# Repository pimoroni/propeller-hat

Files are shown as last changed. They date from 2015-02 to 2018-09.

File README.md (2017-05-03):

Propeller HAT

Propeller HAT, the 8-core microcontroller add-on for your Raspberry Pi.

Available now from Pimoroni: http://shop.pimoroni.com/products/propeller-hat



Propeller HAT is licensed under a Creative Commons Attribution-ShareAlike 4.0 International License.: http://creativecommons.org/licenses/by-sa/4.0/

### Features

* 8-core Parallax Microcontroller on-board
* 30 IO pins broken out, serial data/programming connection to Pi
* 20 Pi pins broken out for communications/ease of access
* 170pt breadboard for experimentation
* Python quick start library with PWM/Servo and GPIO libraries

### Getting started

For instant-gratification you can try the Propeller HAT IO libraries:

* [IO using Serial](documentation/Serial-IO.md)
* [IO using i2c](documentation/IO.md)
* [PWM for LEDs/Servos](documentation/PWM.md)

You'll need Propeller IDE to start programming your Propeller HAT:

* [Propeller IDE Getting Started](/documentation/Propeller-IDE-Getting-Started.md)

## Propeller IDE Installation

As always, we've made it super-easy for you to get all the software you need with a nifty one-line installer. To run it fire up Terminal which you'll find in Menu -> Accessories -> Terminal on your Raspberry Pi desktop like so:

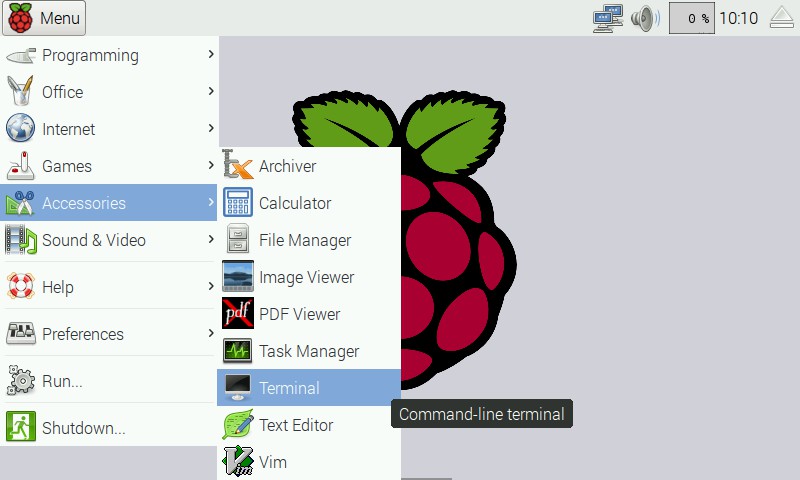
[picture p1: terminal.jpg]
Finding the terminal


In the new terminal window type:

```bash
curl -sS get.pimoroni.com/propellerhat | bash
```

This will install a fairly recent version of the Propeller IDE but if you'd like you can head over to [www.lamestation.com/propelleride/](http://www.lamestation.com/propelleride/) and grab the latest
version of Propeller IDE for the Raspberry Pi, which may be newer than the one installed by the one-line installer.

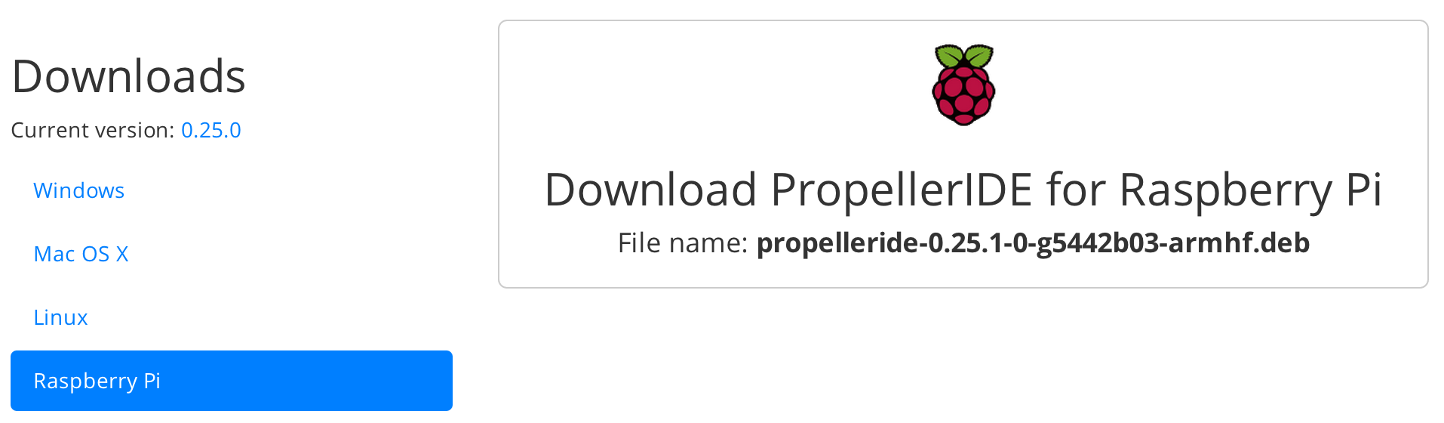
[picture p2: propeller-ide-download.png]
Propeller IDE download


It's easier if you grab the right URL, and use the wget command on your
Raspberry Pi to download it. For example:

```bash
wget https://github.com/parallaxinc/PropellerIDE/releases/download/0.36.7/propelleride-0.36.7-armhf.deb
```

Once downloaded, you can install it with:

```bash
sudo dpkg -i propelleride-0.36.7-armhf.deb
```

### Documentaton & Support

* Tutorials - https://learn.pimoroni.com/propeller-hat
* GPIO Pinout - https://pinout.xyz/pinout/propeller_hat
* Get help - http://forums.pimoroni.com/c/support

### Repository Contents

#### Documentation

Everything you need to get started with Propeller IDE and your first
SPIN program.

#### Software

Suport software and Python-based uploader tool.

* python - Python library for Propeller HAT with PWM and GPIO functions
* sidplay - Play SID tune dumps with Propeller HAT
* p1load - Installer and binary for Pi-compatible p1load

#### Datasheets

Datasheets for Parallax Propeller and Crystal Oscillator.

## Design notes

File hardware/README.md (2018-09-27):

# Propeller HAT Hardware

## License



Propeller HAT is licensed under a Creative Commons Attribution-ShareAlike 4.0 International License.: http://creativecommons.org/licenses/by-sa/4.0/

#### This license covers:

* Propeller HAT board design and schematic layout - Propeller-HAT.brd, Propeller-HAT.sch

#### This license does *not* cover:

* The Parallax Propeller chip itself<sup>1</sup>
* Supporting ICs and components used on the Propeller HAT
* Logos or silkscreen artwork

<sup>1</sup> The Parallax Propeller is licensed under the GNU GPL 3.0, you can find the HDL source to the microcontroller, plus more information, here: http://www.parallax.com/microcontrollers/propeller-1-open-source

#### This license allows you to:

* Share — copy and redistribute the material in any medium or format
* Adapt — remix, transform, and build upon the material for any purpose, even commercially.

#### However, you must:

* give appropriate credit, provide a link to the license, and indicate if changes were made. You may do so in any reasonable manner, but not in any way that suggests we endorse you or your use.
* distribute your contributions under the same license as the original if you remix, transform, or build upon this material.

## Pinout

All Propeller IO is broken out in the horizontal pin headers. Note: The TX/RX pins, while available to the IC as general purpose IO pins normally, are tied to the GPIO of the Raspberry Pi and thus cannot be used.

Pins A29 and A28 are EEPROM SDA and SCL respectively. A 24LC512-I/P<sup>1</sup> EEPROM is recommended, and will require 10K pullup resistors. Once added, the Propeller will allow uploads to EEPROM and will load its contents upon boot.

## Bill Of Materials

* 1 x P8X32A-Q44 - QFP Parallax Propeller IC
* 1 x ABLS3-6.000MHZ-D4Y-T - 6Mhz Crystal Oscillator
* 1 x AP7333-__SRG - 300mA, 3.3V Voltage Regulator
* 1 x EEPROM - for Raspberry HAT compatibility
* 1 x 40PIN Low Profile Female SMD Header
* 1 x 10K Resistor R0603
* 2 x 4.7K Resistor R0603
* 1 x 1K Resistor R0603
* 4 x 0.1uF Capacitor C0603K
* 2 x 1uF Capacitor C0603K

## Crystal

6Mhz was chosen for a conservative overclock, but should be well within the range of values a P8X32A chip can tolerate under normal hobbyist operating conditions. PropellerHAT can operate on a 4Mhz-8Mhz variant of the ABLS3 Crystal. Typical clock speeds at a PLL of 16 to 2x include:

| Xin  | 16x | 8x | 4x | 2x |
|---|---|---|---|---|
| 8Mhz | 128Mhz* | 64Mhz | 32Mhz | 16Mhz |
| 6Mhz | 96Mhz | 48Mhz | 24Mhz | 12Mhz |
| 5Mhz | 80Mhz | 40Mhz | 20Mhz | 10Mhz |

*Speed not supported or recommended.

* [ABLS3 Crystal Oscillator datasheet](/datasheets/Crystal-OSC-ABLS3-25529.pdf)

* <sup>1</sup> http://uk.mouser.com/ProductDetail/Microchip-Technology/24LC512-I-P/?qs=JmwSjbzn2OL8zYUOM6epRw%3D%3D

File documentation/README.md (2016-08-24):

#Propeller HAT Documentation

Ahoy! If you're reading this, you're probably the proud over of a shiny new Propeller HAT.
If so, thanks for picking one up, and I hope you enjoy discovering the quirks of this powerful little Micro Controller as much as I did.

##Propeller IO Quick Start

The Propeller HAT Python library includes a set of IO modules which, when loaded, automatically flash your Propeller HAT with firmware to handle things like PWM and basic Input/Output.

The best way to explorer these is to install the Propeller HAT library and run one of them:

```bash
sudo pip install p1
sudo python -im p1.pwm
```

This loads p1.pwm, a PWM library for Propeller HAT which gives you 30 software PWM pins handled by the Propeller itself and uninterrupted by anything you might do on the Pi.

#What next?

* [Propeller IDE Getting Started](/documentation/Propeller-IDE-Getting-Started.md) - Learn how to install Propeller IDE

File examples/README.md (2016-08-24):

#Documentation Source

The files you find here are complete examples from the Propeller HAT documentation.

To upload one to your Propeller HAT you must first compile it into a binary, like so:

```bash
openspin Diving-into-multicore.spin
```

Then you can load it with propman, like so:

```bash
propman Diving-into-multicore.binary
```

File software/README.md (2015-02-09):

Raspberry Pi Propeller HAT
==========================

The tools provided in this library are specifically designed
for the Raspberry Pi Propeller HAT and may require adaptation
to function with any other platforms.

The PropellerHAT library serves a dual purpose, as a Python
binary uploader for the Propeller and as a library which can
be imported into your Python modules to prepare the Propeller for
specific use-cases such as emulating an IO expander.

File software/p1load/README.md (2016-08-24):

#p1load

p1load has now been superseded by propman, which is installed by the Propeller IDE since version 0.30.0

There is therefore little reason to use p1load as an alternative. However, it is kept in this repository in case it could be useful to users who must stick to using an older version of the IDE, or prefer not to install the IDE or compile propman from source.

To use, simply run:

```bash
./install
```
then:

```bash
p1load binary_file.binary
```

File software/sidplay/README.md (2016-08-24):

#SIDPlay

This example uses SIDcog Serial Slave and a serial streamer written in C to stream raw SID register dumps to Propeller HAT.

You will need to install wiringPi!

```bash
git clone git://git.drogon.net/wiringPi
cd wiringPi
./build
```

To upload the sid player, run:

    ./sidplay.py

To play a SID dump, run:

    ./sidplay SID_File [Frequenzy_HZ Duration_Sec]

To create a valid dump file you will need the SID dumper tool from here: http://forums.parallax.com/showthread.php/118285-SIDcog-The-sound-of-the-Commodore-64-!-%28Now-in-the-OBEX%29

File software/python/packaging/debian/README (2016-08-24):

README

Propeller HAT brings the 8-core Parallax Propeller microcontroller to the Raspberry Pi. You can program and talk to it over Serial using the Propeller IDE.

Learn more: https://shop.pimoroni.com/products/propeller-hat
For examples run: `curl -sS get.pimoroni.com/propellerhat | bash`

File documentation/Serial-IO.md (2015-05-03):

#Propeller HAT Serial IO

Propeller HAT Serial IO is a Python library which flashes your Propeller HAT with
a 30-pin, general purpose Serial GPIO driver.

It lets you control 30 pins from A0 to A29, setting them as Inputs or Outputs and
changing them from High to Low with simple serial commands.

##Prerequisites

Propeller HAT Serial IO doesn't require any special hardware setup.

##Usage

Propeller HAT Serial IO talks to your Raspberry Pi over serial.

###Reading Pins

Every time an INPUT pin value changes, it will report its state.
Each pin belongs in a bank of 5 pins, and all 5 of these pins will
have their state reported together. So, if 5 pins on one bank change
you will see one byte of update data, if 5 pins on 5 different banks
change you will see 5 bytes of update data.

**You can read the update data as follows:**

Bit 0 - 2 | 3  | 4  | 5  | 6  | 7 
----------|----|----|----|----|----
Bank #1-6 | p1 | p2 | p3 | p4 | p5

The first 3 highest bits ( 0b11100000 ) are the bank number, starting at
1 and ending at 6.

The last 5 bite ( 0b00011111 ) represent the state of each pin in that bank.
1 = HIGH and 0 = LOW.

So:

* Bank = (BYTE & 0b11100000) >> 5
* Pin states
  * 0 = BYTE & 0b00010000
  * 1 = BYTE & 0b00001000
  * ... and so on

**Pins are mapped into banks like so:**

Bank # | Pins
-------|-----------
1      | A0  to A4
2      | A5  to A9
3      | A10 to A14
4      | A15 to A19
5      | A20 to A24
6      | A25 to A29

###Writing Pins

To change pin direction and value, you must send a single byte
containing a 3-bit CMD on the highest 3 bits, and a 5-bit pin
number to tell the Propeller which pin to act upon.

Bit      | 7 | 6                        | 5                        | 4 to 0
---------|---|--------------------------|--------------------------|--------
Function | 0 | 0 = Direction, 1 = State | 0 = In,Low, 1 = Out,High | Number of pin to change from 0-29

* 0b00100001 = Set pin 1 to OUTPUT
* 0b01100001 = Set pin 1 to HIGH

Pins 30 and 31 are not read or written because these are used for Serial communication.

###Request FW version

Setting bit 7, the highest CMD bit, high switches to CMD mode. At
the moment this will always cause the Propeller HAT to emit the
FW_VERSION constant stored in the binary.

Bits 6 to 0 in this instance are reserved for future functionality.

##Library Reference

```python
p1.serialio.mode(pin, mode)
```

Change the mode of pin pin to either mode 1, OUTPUT or mode 0, INPUT. You can use
p1.io.OUTPUT and p1.io.INPUT constants for this.

```python
p1.serialio.write(pin,value)
```
Write a value to pin. 1 = HIGH, 0 = LOW.

```python
p1.serialio.read(pin)
```
Read a value from pin. Returns 1 if the pin is read as HIGH or 0 if it is low.

**Note:** This actually reads values from a list stored in Python, since the Propeller
automatically emits updated pin states and no explicit read command exists.

Here's a quick example of using p1.serialio in an interactive Python shell. The
-i command for Python runs in interactive mode, and the -m command will load
a specific module, in this case p1.serialio, saving typing out "import p1.serialio".

```bash
pi@raspberrypi ~ $ sudo python -im p1.serialio
Setting up Propeller HAT
Connected (version=1)
Sending code (1084 bytes)
>>> mode(2,1)
>>> write(2,1)
>>> mode(3,1)
>>> write(3,1)
>>>
```

**Note:** The Propeller does not have configurable internal pull-up/down resistors
on any of its IO pins. If you want to use an IO pin as an input, an appropriate
pull resistor is recommended to prevent it from floating.

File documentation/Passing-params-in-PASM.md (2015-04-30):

<!--
---
title: Passing params in Propeller Assembly
handle: passing-params-propeller-pasm
type: tutorial
summary: A detailed guide to passing one or more params into a Propeller Assembly ( PASM ) program running on Propeller HAT.
author: Phil Howard
products: [propeller-hat]
tags: [Propeller HAT, Raspberry Pi, Microcontroller, PASM, Programming]
images: [images/tba.png]
difficulty: Advanced
-->
#Passing params in PASM

This example shows you how to pass a start address for a set of paramaters to your new Cog as the boot parameter. You can
then read each paramater, as a long or a byte, by incrementing the supplied Address and using the rdlong and rdbyte instructions
to retrieve them from the Hub.

This is a pretty standard way to bootstrap your Cog with all the information it needs to do its job, and is also a handy way
to provide arrays or single memory locations where the Cog can deposit the result of its work.

For example, you could define a LENGTH var, followed by a LED_PATTERN var and produce code in PASM which reads each byte from
LED_PATTERN in turn and flashes the LEDs. Perhaps we'll cover such a thing later.

For now, a simple example:

```spin
CON
  _CLKMODE = xtal1 + pll16x
  _XINFREQ = 6_000_000
  
VAR
  long MY_PIN_1, MY_PIN_2 ' These will appear next to each other in memory
  
PUB main
  MY_PIN_1 := |< 0		       ' Set our first pin to a bitmask for A0
  MY_PIN_2 := |< 1		       ' And our second for A1
  cognew(@blink, @MY_PIN_1)            ' Supply the address of the first parameter  
  
DAT
        org         0
blink   mov         addr,       par     ' Load our address from the boot param
        rdlong      Pn,         addr    ' Read the first pin number
        add         addr,       #4      ' Increment addr by 1 long ( 4 bytes )
        rdlong      Pn2,        addr    ' Read the second pin number
        
        or          dira,       Pn	' Set up pins as outputs
	or	    dira,	Pn2     ' It's good to do stuff while we're waiting
					' for the Hub to come back around, since we
					' only just synced for a rdbyte!
        
        rdlong      Delay,      #0      ' Prepare the delay
        mov         Time,       cnt	' Prep the wait time
        add         Time,       #9	' Add the minimum wait time
        
:loop   waitcnt     Time,       Delay   ' Start blinking!
        xor         outa,       Pn
        xor         outa,       Pn2
        jmp         #:loop
        
Pn      res         1			' Store our first LED pin
Pn2     res         1			' Store our second LED pin
Addr    res         1			' Store our parameter address
Delay	res	    1			' Store the delay increment
Time	res	    1			' Store the current time for wait
        fit
```

####Breaking it down

I'm going to assume you've read [My First Pasm](/documentation/My-first-PASM.md) and skim over much of the basics.

`long MY_PIN_1, MY_PIN_2`

In our PASM code, we're declaring two variables next to each other. These will appear adjacent to each other in HUB memory as two sets of 4 bytes, or 2 longs. These are the longs we want to copy to our COG!

```
MY_PIN_1 := |< 0
MY_PIN_2 := |< 1
```

In our `main` method, we're setting the values of `MY_PIN_1` and `MY_PIN_2` to be bit masks, by using our old friend the bitwise decode operator `|<`. Practically speaking, this will convert `0` to `%0` and `1` to `%10` etc.

We use bit masks because these can be `or`'d against our output registers to flip those bits to 1. Or `xor`d to toggle them.

It's worth noting that in SPIN and PASM you use `%` to denote a binary number, like `%10101010` and `$` to denote a hexadecimal number like `$AA`.

`mov addr, par`

The very first line of our PASM ( remember that "blink" in this case is a label, and not part of the instruction ) deals with
the `par` register. This register always starts off containing the parameter that's passed into it via `cognew`.
In this case we've passed it the Hub address of `MY_PIN_1`, and it can use this address to locate that value in the Hub when it
wants to read it. 

`rdlong      Pn,         addr`

The second line executes what's known as a HUB instruction. The instruction `rdlong` waits for the HUB to come around, then reads a long ( 4 bytes ) into the target location. In this instance Pn is our memory location within the COG and is where we want to copy the value of `MY_PIN_1`.

`add         addr,       #4`

Now that we've read one long from HUB memory, we want to advance to the next one. Addresses are byte-aligned, which means we can read one byte at a time. Since we want the next 4 bytes, and not just the last 3 of the previous long plus the first of the next long, we'll increment our `addr` register by 4. 4 bytes = 1 long.

`rdlong      Pn2,        addr`

Now we've got a pointer to `MY_PIN_2`, which is a long in memory right next to `MY_PIN_1` we can use the `rdlong` instruction to read it into `Pn2`.

Hooray. We've successfully copied two setting values from HUB memory into our COG!

`or          dira,       Pn`

In this next line we're simply `or`ing the value of `Pn` against `dira`- this sets it as an output. The bit that's set in the `Pn` mask will flip to 1 in the output register. For example `0000 or 0100 = 0100`.

Everything else you should remember from [My First Pasm](/documentation/My-first-PASM.md), we set up a loop using `waitcnt` and `jmp` and use `xor` ( `1 xor 1 = 0, 0 xor 1 = 1` ) to blink the LEDs.

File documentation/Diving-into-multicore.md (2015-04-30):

<!--
---
title: Multicore SPIN programming on Propeller HAT
handle: writing-your-first-multi-core-spin-program
type: tutorial
summary: Learn how to use the Propeller's multi-core architecture to your advantage
author: Phil Howard
products: [propeller-hat]
tags: [Propeller HAT, Raspberry Pi, Microcontroller, SPIN, Programming]
images: [images/tba.png]
difficulty: Intermediate
-->
#Diving Into Multicore

You probably didn't pick up Propeller HAT because it was some ordinary, run-of-the-mill Microcontroller board. No siree.
You want to take advantage of those 8 cores and play to the Propeller's strengths.

Well, fortunately, it's really not all that hard.

###What's a cog, got to do, got to do with it?

In the world of Propeller, where almost everything is a pun based on the name of the chip, you'll often find the cores
referred to as "cogs". The Propeller has 8 cogs, and ( wait for it... ) a "hub".

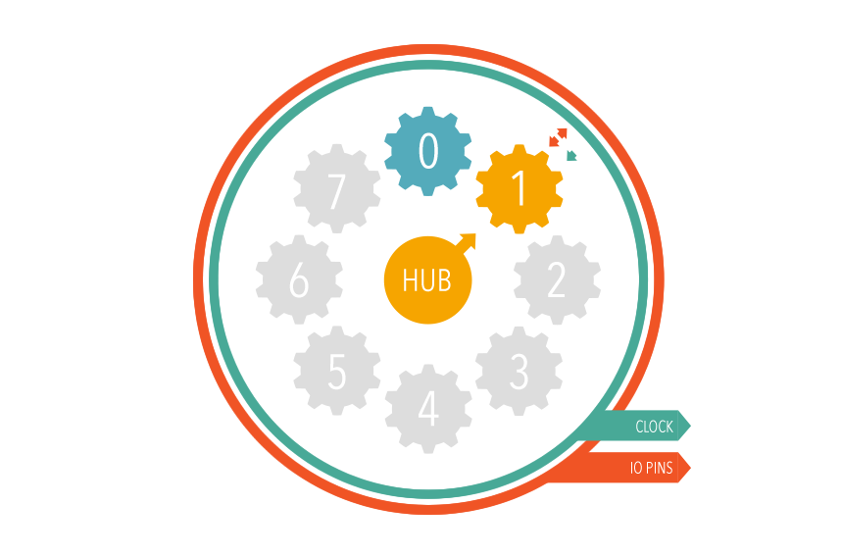
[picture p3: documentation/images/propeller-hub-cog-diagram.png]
Propeller HUB and Cog Diagram


####The Hub

The Hub is the central controller of the Propeller, it houses the lion's share of the chips memory/storage - 8192, 32-bit
longs ( also known as 32kb or 32,768 bytes ). The Hub's job is to dish out tasks to the Cogs, control their access to its
memory and make sure they don't fight over resources or tread on each other's toes.

In other words, the Hub is the boss! What it doesn't have, however, is the ability to run code. The Hub sits in its tiny
silicon throne and dishes out commands, but it can't execute any itself. The Hub relies wholly and totally on the Cogs to carry
out their instructions and only gets involved when they need to communicate, share data or receive new sets of instructions.

The Hub also has some other fancy features, such as configuration registers and lock bits- we won't worry about those yet!

####The Cogs

Now. Onto the Cogs. Each Cog has 512, 32-bit longs ( also known as 2kb or 2048 bytes ) of memory. This memory serves as both
storage for the instuctions that Cog has been told to execute, and as running memory for remembering what it's doing.

2kb is a pretty decent amount of memory for a Cog, but you have to be mindful that the larger your running code is, the less
space will be available for it to store what it's working on. Think of it like filling a frying pan- the more food you pop
into the frying pan the less space you have to stir it!

Alongside the memory, each Cog has its own CPU capable of executing the instructions its given, it also has its own
counters and video generator- but we'll worry about those later too.

The most important thing to remember is that each one of the 8 Cogs has its own DIRA and OUTA register for setting the
direction and output state of all 32 IO pins on the Propeller. When you're passing a function or code to a Cog you need
to make sure that the Cog sets up its own DIRA register, since setting the direction of a pin elsewhere will likely happen
in another Cog and lead to confusing results!

###Now, for some code!

```spin
CON
  _CLKMODE = xtal1 + pll16x
  _XINFREQ = 6_000_000

  MY_LED_PIN = 0 ' Use pin A0
  SECOND_PIN = 1 ' Use pin A1

VAR
  long stack[128] ' Allocate 128 longs of stack space for our new COG

PUB main
  cognew(blink_second_pin, @stack) ' Start a new COG
    
  DIRA[MY_LED_PIN] := 1 ' Set the LED pin to an output

  repeat ' Repeat forever
    OUTA[MY_LED_PIN] := 1   ' Turn the LED on
    waitcnt(cnt + clkfreq)  ' Wait 1 second 
                            ' cnt is the clock tick counter, 
                            ' clkfreq is the number of clock ticks in a second
    OUTA[MY_LED_PIN] := 0   ' Turn the LED MY_LED_PIN
    waitcnt(cnt + clkfreq)  ' Wait 1 second

PUB blink_second_pin
  DIRA[SECOND_PIN] := 1
  
  repeat
    OUTA[SECOND_PIN] := 1    ' Turn second LED on
    waitcnt(cnt + clkfreq/2) ' Wait half a second
    OUTA[SECOND_PIN] := 0    ' Turn second LED off
    waitcnt(cnt + clkfreq/2) ' Wait half a second
```

You'll notice that the simple act of launching a new Cog has introduced a lot of extra code to our program. Let's
break it down again...

####blink_second_pin

The majority of this is the work we actually want the Cog to do, which is all contained within the PUBlic method
`blink_second_pin`. It's very similar to our main public method because it's blinking another pin.

To make it clear that the second Cog is running, we pick a different pin, and a faster blink rate.

As before, we use a CONstant to define which pin we'd like to blink, in this case in A1.

####clkfreq/2

Since `clkfreq` is the number of clock ticks in a single second, we can incur a wait of half a second simply by
dividing it by two.

####DIRA and OUTA strike again

Every single Cog has its own DIRA and OUTA registers, so it's absolutely imperative to remember to set the direction
of the pin you want to use before trying to change its value. If you forget to set a pin to an output 
(`DIRA[PIN] := 1`) then it wont output its value when you change it (`OUTA[PIN] := X`).

####cognew

This example introduces another feature of SPIN, the `cognew`<sup>1</sup> command. Cognew does what it says on the tin, and
initiates a new Cog to run the SPIN method that you pass it. Cognew has a cousin known as `coginit` which also runs
a spin method in a Cog, but instead of finding the first available unused Cog it gives a new task to the one you specify.

At this point, it's important to note that the code calling `cognew` is running in a *Cog* and not the *Hub*. So this means you have 7 remaining Cogs to run 7 additional tasks.

The `cognew` command has a second required parameter, the stack pointer...

####stack

A new `VAR` section has made its way into this example too. In this instance our only variable is the
stack<sup>2</sup> we want to reserve for our new Cog. This is a portion of Hub memory which the Cog can use to 
store temporary data that it needs to carry it its task.

When we call `cognew` we pass it the stack variable, the `@` prefix gives us the address of our `stack` array,
rather than its value. Giving it the address means that the newly iniated Cog will know that it's safe to store
values at this location. The stack should always be sized appropriately for whatever task the Cog is allocated.
At this stage we don't really care about optimisation, so we'll use a "safe" and spacious stack that's 128 32-bit
longs in size.

If you've ever come across the term "stack overflow", it's what happens when an application tries to use more stack
space than there has been allocated for it- this means it'll try and store things in memory locations after the
stack which have potentially been reserved for something else.

#Wiring up your Propeller HAT

To see the result of this code, you'll need a couple of LEDs plugged into outputs A0 and A1, like so:

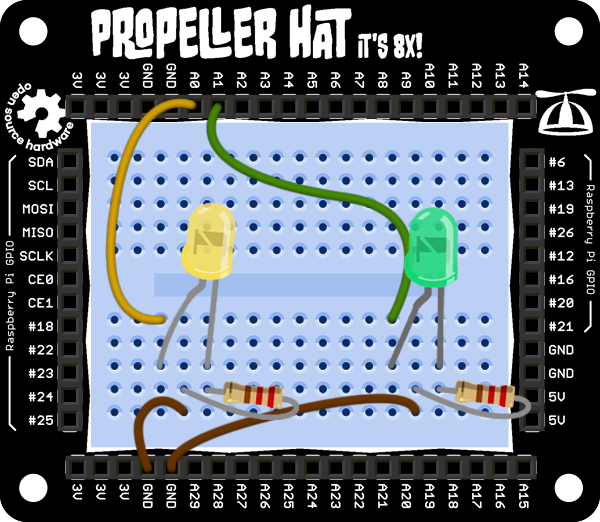
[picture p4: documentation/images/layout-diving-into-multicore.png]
Propeller Multicore Layout


#Further Reading

* <sup>1</sup> A little more detail about Cogs: http://www.parallax.com/propeller/qna/Default.htm#QnaTopics/QnaCogs.htm
* <sup>2</sup> Learn more about the need for Stack on Propeller Cogs: http://www.parallax.com/propeller/qna/Default.htm#CodeTeqTopics/StackSpace.htm

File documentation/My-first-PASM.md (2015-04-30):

<!--
---
title: Writing your first PASM program
handle: writing-your-first-pasm-program
type: tutorial
summary: A brief introduction to Propeller Assembly, and your first PASM program
author: Phil Howard
products: [propeller-hat]
tags: [Propeller HAT, Raspberry Pi, Microcontroller, PASM, Programming]
images: [images/tba.png]
difficulty: Advanced
-->
#My First PASM

If you're anything like me, you'll see PASM ( Propeller Assembly ) as a looming challenge, begging to be tackled 
and surmounted whether or not it proves to be at all useful in your Pi projects.

Programmers can certainly succumb to "challenge accepted" moments, and PASM is one of those.

##Blink

Like all languages, the canonical way to get started is with a simple and easy blink example. Let's have a look
at one in PASM. What we'll actually see is a small SPIN program loading up a new Cog with the PASM we want to run.
All the code you run on a Propeller will start with a Cog running SPIN.

```spin
CON
  _CLKMODE = xtal1 + pll16x
  _XINFREQ = 6_000_000
  
  MY_LED_PIN = 0
  
PUB main
  cognew(@blink, 0) ' Start a Cog with our assembly routine, no stack 
                    ' is required since PASM requires we explicitly 
                    ' assign and use memory locations within the Cog/Hub
DAT
        org     0
blink   mov     dira,   Pin       ' Set our Pin to an output
        rdlong  Delay,  #0        ' Prime the Delay variable with memory location 0
                                  ' this is where the Propeller stores the CLKFREQ variable
                                  ' which is the number of clock ticks per second
        mov     Time,   cnt       ' Prime our timer with the current value of the system counter
        add     Time,   #9        ' Add a minimum delay ( more on this below )
:loop   waitcnt Time,   Delay     ' Start waiting
        xor     outa,   Pin       ' Toggle our output pin with "xor"
        jmp     #:loop            ' Jump back to the beginning of our loop
        
Pin     long    |< MY_LED_PIN     ' Encde MY_LED_PIN to a bit mask
Delay           res     1
Time            res     1
        fit
```

Whew! That's a lot to take in. While at first glance the PASM code may look like incomprehensible nonsense,
it's actually a lot easier to understand than it looks. Assembly doesn't have many of the constructs we take
for granted in most high level programming languages, and that means it doesn't have those complexities either.

Most of these Assembly commands are simply moving a number from one place to another, or performing an operation
upon two memory locations. Once you get a simple Blink program running, it becomes easier to experiment with how
other instructions affect, for example, your Pin value.

Onward to the explanation...

####cognew

You'll notice, if you've read through the Multicore tutorial, that our cognew command is ever so slightly different
this time around.

This is because PASM is wholly different to SPIN in how it operates, and is much more explicit about how memory is
used. SPIN needs a stack to store various snippets of information as it goes about its business, and what it stores
is completely hidden from the programmer, it's a high-level language.

PASM, on the other hand, only stores things where you tell it, when you tell it and how you tell it.

The second parameter in this instance becomes the read-only parameter passed into the new Cog. You can specify a
single number, a complicated 32-bits long bitfield, or just give it the memory address for a handful of parameters
stored in the Hub. This is all far too advanced for our first blink, though, so we'll stick with 0.

####The Assembly

The PASM code in this example is quite the monster, even for a simple Blink. We'll tackle it line by line and I'll
try to explain everything to the nth degree. Grab a drink and a snack, and sit tight!

```spin
DAT
```

All PASM is stored within the DAT section of its parent SPIN program. This is the easiest place to store PASM source
which everyone can see and modify, but it's not the only way. You could use an array of longs to store
compiled PASM instructions, or you could create PASM instructions on the fly ( please don't! for your own sanity! ).

```spin
org 0
```

This is some PASM copypasta that you'll find at the top of most, if not all, blocks of PASM code in some form or 
another. It simply states that the following PASM code should start at Cog RAM addr 0.

```spin
blink   mov     dira,   Pin
```

There's a lot going on in this line, but it's easy enough to break down.

The `blink` part is a label, this is a little note to the compiler telling it that we want to keep track of this
point in the program so we can find it later. This label can be passed into `cognew` to tell it where to locate our PASM. It can also be jumped to in PASM itself, you'll see this later.

Next comes the actual instruction: `mov dira, Pin`. The `mov` part is a simple mnemonic, a text name for a numerical
instruction that the Propeller can understand. If you hadn't guessed, it means "move" although it actually copies.

The rest of the instruction is made up of our destination, `dira` which is the address ( not the value ) of the
DIRA register, the very same one we use in SPIN. And, finally, the address of our source `Pin` which is a 32bit integer containing the pin mask we want to toggle.

So this instruction is telling the Propeller to `mov` the value of memory location `Pin` into register `dira`. Well,
 copy, since the Pin value remains unchanged.

Bear in mind that we're blatting the whole register by moving Pin into it, so our Pin will be the *only* output.

A far more appropriate instruction would be `or dira, Pin`, which would turn the Pin to an output if its not one,
and would otherwise leave it unchanged.

```spin
rdlong  Delay,  #0
```

Next up is a Hub access instruction. Propeller Assembly includes special instructions for accessing Hub memory.
This particular one, `rdlong`, reads a long ( a 32bit integer ) into its target from a source memory location.

In this instance `Delay` is our target, a long we've reserved for our use, and the source is `#0` which is a
*literal* memory address. So, we're loading Delay from Hub memory location 0. This just so happens to be where the
Propeller keeps the CLKFREQ value, which is the number of clock ticks in a second. Using this, we can create a 1sec
delay later.

```spin
mov     Time,   cnt
```

Just like our earlier `mov` instruction, we're copying the value of one memory address or register into another.

In this case we're priming `Time` with the value of the system counter, for which there's a handy shortcut `cnt`
so you don't have to remember its numeric memory location.

```spin
add     Time,   #9
```

Now for an `add` instruction. This one should be easy to understand. We're adding the literal value 9 ( we indicate
that it's not an address by prefixing with # ) to our Time variable.

But, why on earth are we doing this? The reason is perplexing, but simple once you understand it.

The `waitcnt` instruction in PASM will wait until the `cnt` register equals the value we give it. We're passing
it the value of `Time` for its first wait, if this value simply equalled the system counter then the very act of
calling `waitcnt`, which itself takes time, will cause us to miss the value we're looking for.

> Imagine I gave you a piece of paper with the number 30 on it, and told you at exactly 30 seconds past 
to wait until the clock next shows 30 seconds. By the time I've finished telling you what to do it's going to be
at least 32 seconds past- so you'll wait nearly a whole minute instead of the 30 seconds I wanted.

> When waitcnt misses a particular value of cnt, this is more or less what's happening!

A more succinct way to write this line would be:

```spin
add     Time,   Delay
```

Which causes our first `waitcnt` delay to be about 1 second, instead of the minimum possible delay. However I
deliberately left this minimum wait to illustrate a common tripping point in PASM.

```spin
:loop   waitcnt Time,   Delay
```

Now we start waiting. This line does two things.

* First `waitcnt` will wait until the system counter matches the value we've specified in `Time`.
* Second, the value of `Delay` will be added to `Time` to create the next value to wait for.

Because `Delay` is added to `Time` for us, there's no need to do it manually within the loop, and the next
time we call `waitcnt` in the same way, we'll handily get another 1 second delay.

This is, of course, unless all the things we've decided to do within the loop take more than the delay time!

The `:loop` prefix on this line is another label. Using ':' to prefix a label is a handy way of making it
obvious that it's a label, and not a variable, register address or instruction mnemonic. We've labelled this
line because, in order to loop, we want to jump back to it later.

The word "loop" is not required, you can make this label ":monkeys" if you want!

```spin
xor     outa,   Pin
```

This line is where the magic happens. We're finally setting a value to our output register `outa`.
Using `xor` is a *really* lazy way of toggling our output pin, since it literally means "exclusive or".

So, if our pin is on, we get:

`1 xor 1 = 0`

And if our pin is off, we get:

`0 xor 1 = 1`

And so on!

The thing to remember here is that xor is operating upon the whole 32bit register, so `xor` is a really handy
way to toggle a pin using a bit mask, without affecting the others.

```spin
jmp     #:loop
```

And now we're finally jumping back to the label we set earlier, completing the loop and resulting in the `xor`
on our output register being run about once a second.

You can `jmp` to any memory address you like, but using a label makes it much easier to keep track of where the 
jump is going.

```spin
Pin     long    |< MY_LED_PIN
```

This line creates a new, long type variable called Pin which we're assiging with a bitmask decoded from our
MY_LED_PIN constant. The decode operator "|<" will turn 1 into 0001, 2 into 0010, 3 into 0100 and so on.

This is the bitmask we use when calling `xor` against the output register. Remember:

* `0001 xor 0001 = 0000` ie: turns pin On
* `0000 xor 0001 = 0001` ie: turns pin Off

```spin
Delay           res     1
Time            res     1
```

These two lines reserve longs of memory using the `res` directive. We can reserve 1 or more longs, but since Time
and Delay both fit into a single 32-bit integer we'll only use 1.

`res` is a directive, not an instruction, this means it's evaluated by the compiler and never run as PASM. Upon
evaluation it just leaves gaps in the Cog memory and gives them the friendly names, symbols, which we can refer
to them by in our code.

The symbols ( or labels ) Delay and Time don't exist as far as PASM is confirmed, they're just friendly names
for us to re-use that represent memory addresses.

In plain English, these commands mean "leave the next memory address empty and call it Delay so we can use it elsewhere".

```spin
fit
```

This final directive isn't essential, specially when we're dealing with such small amounts of PASM code, but it's
useful to remember. `fit` is another instruction to the compiler, it simply asks "does all the PASM we've written
actually fit into Cog RAM?"

`fit` will generate a compiler error if we've written too much code to fit into a single Cog. At this point we'd
need to either cut down the code by optimising it, or split its jobs over muliple Cogs.

##Whew!

Well, that was an explanation marathon. Go and cool off your brain for a minute, and then get ready to compile
and run your code. For this example you can use the same layout we used in the SPIN blink example:

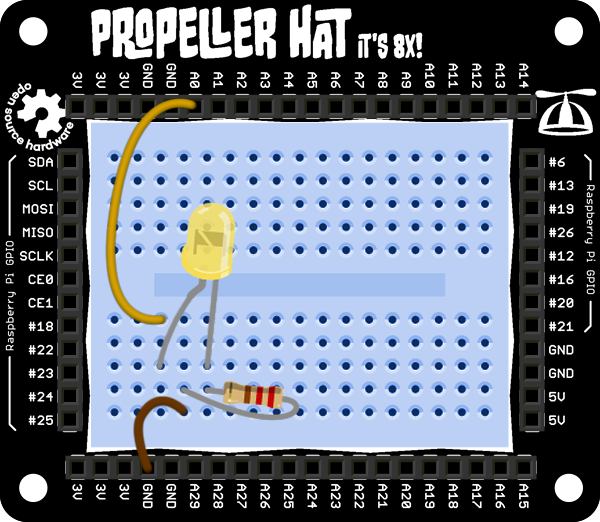
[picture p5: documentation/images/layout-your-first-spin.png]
Propeller Blink Layout


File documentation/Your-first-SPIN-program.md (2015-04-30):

<!--
---
title: Writing your first SPIN program
handle: writing-your-first-spin-program
type: tutorial
summary: A brief introduction to SPIN, the language of the Propeller, and your first Blink program
author: Phil Howard
products: [propeller-hat]
tags: [Propeller HAT, Raspberry Pi, Microcontroller, SPIN, Programming]
images: [images/tba.png]
difficulty: Intermediate
-->
#Your first SPIN Program

###What is SPIN?

SPIN ( get it? Spin a Propeller? ) is the language of the Propeller chip. It's actually unique to the Propeller,
found nowhere else. Surprisingly it's also an interpreted language. This means it's not actually compiled into a set of
instructions that the Propeller chip understands natively, but is instead run in a tiny interpreter inside the chip<sup>1</sup>.

Propeller's native language is PASM, or "Propeller Assembly." It's a little beyond the scope of your Propeller HAT journey,
though, so we'll ignore it for now.

###What makes up a SPIN program?

Every SPIN program consists of functions, variables, constants and data indicated by "Block Designators". These concepts
are common to most programming languages, but SPIN is strict about how and where they appear.

The block types in SPIN are:

* `CON` - Declares a block of Constants, such as `LED_PIN = 1`
* `VAR` - Declares a block of Variables, such as `led_state := 0`
* `OBJ` - Declares a block of Objects, these load external code ( a bit like Python's import ) for you to use in your program
* `PUB` - Declares a single public method- if you were loading your code as an object, you could call this method
* `PRI` - Declares a single private method- this would be hidden when loading your code as an object
* `DAT` - Declares a block of data, this is often used to store chunks of Propeller Assembly

In Propeller IDE, each of these blocks will be displayed with its own distinct background colour, and adjacent blocks of
the same kind will have alternating shades to differentiate them. This gives most SPIN examples their colourful and
somewhat controversial looks:

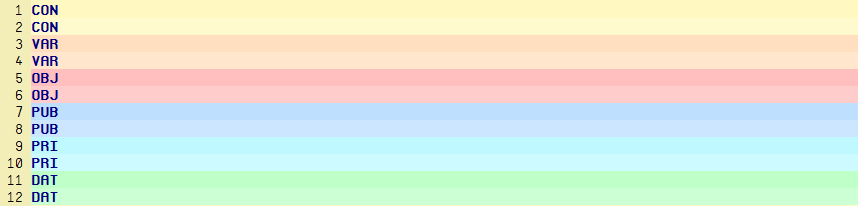
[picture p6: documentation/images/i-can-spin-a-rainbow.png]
I can SPIN a rainbow!


The `CON` block is also used to declare some important settings such as the Clock Mode, and Crystal Frequency, which
let your program know what sort of environment it's running in.

A bare-bones SPIN program might look something like this:

```spin
CON
  _CLKMODE = xtal1 + pll16x
  _XINFREQ = 6_000_000
  
  MY_LED_PIN = 0 ' Use pin A0
  
PUB main
  DIRA[MY_LED_PIN] := 1 ' Set the LED pin to an output
  
  repeat ' Repeat forever
    OUTA[MY_LED_PIN] := 1  ' Turn the LED on
    waitcnt(cnt + clkfreq) ' Wait 1 second 
                           ' cnt is the clock tick counter, 
                           ' clkfreq is the number of clock ticks in a second
    OUTA[MY_LED_PIN] := 0  ' Turn the LED off
    waitcnt(cnt + clkfreq) ' Wait 1 second 
```

Let's break this down step-by-step...

####_CLKMODE and _XINFREQ

These might look like complicated arcane magic at first, but they're really nothing to be worried about.
On Propeller HAT these two lines will always be the same.

`_CLKMODE` is being set with the value `xtal1 + pll16x` to state that we want to use the external crystal oscillator,
and set the system clock to its value, multiplied by 16x using the PLL<sup>2</sup>.

`_XINFREQ` is simply set with the frequency of the external clock. On Propeller HAT we use a 6Mhz crystal, so that's 6000000.
We use understores, which are ignored by SPIN when found in numbers, to make the big number read clearly at a glance.

####Assigning "MY_LED_PIN"

Propeller HAT has 30 user pins from 0 to 29, pins 30 and 31 are tied to your Pi's serial port for communication.

To assign our LED constant we pick one of the available pins ( labelled A0 to A29 on the board ) and use the corresponding
number. Because we're assigning a constant, we use the "Constant Assignment" operator which is simply `=`:

```spin
MY_LED_PIN = 0 ' Use pin A0
```

####DIRA and OUTA

Behind the scenes of Arduino you'll find something very much like these. They are known as Registers. `DIRA` and `OUTA` both refer to physical, 32-bit locations onboard the Propeller chip itself and the values of each bit in these locations correspond directly to the Direction ( `DIRA` ) and Output Value ( `OUTA` ) of each hardware pin.

Think of a register as 32 physical on-off switches which you can change from your code, since this is fundamentally what it is. 

**Note:** In the Propeller world every single core or cog has its own `DIRA` and `OUTA` register, and the values of these are "OR'd" together to form the final direction and output values of each pin. If *any* cog tells a pin to output a 1, that pin will output a 1, and if any* cog sets a pin to an output that pin will be an output. Keep this in mind, or it'll almost certainly trip you up when you start using more than one core!

Here are some of the ways you can assign a state to the output and direction registers:

```spin
OUTA := %00000000_00000000_00000000_00000001
OUTA[0..3] := %1000
OUTA[0] := 1
OUTA[0]~~       ' Set to 1, high
OUTA[0]~        ' Set to 0, low
```

When setting any variable within SPIN you should use `:=` instead of `=` since `=` is the "Constant Assignment" operator
and should only ever be used to assign constants.

I don't use `OUTA[0]~~` or `OUTA[0]~` because I think they're unecessarily obtuse and confusing. `OUTA[0] := 1` and `OUTA[0] := 0` are longer, but easier to understand at a glance.

####repeat

SPIN uses a `repeat` command, this is similar to a for or while loop and there are many ways to change its behaviour which we'll cover in later examples. Right now we'll just use `repeat` on its own to create an infinite loop.

Notice that the lines underneath repeat are indented? This is because, like Python, SPIN uses intentation as syntax (to convey meaning ). In this instance, the indented lines are the ones we want to be repeated. If you're a keen pythonista, you should also take note that there's no ":" on the end of "repeat".

```spin
repeat
  ' Everything you want to be repeated
  ' should be indented under the repeat command
```

####waitcnt

SPIN's `waitcnt` command, meaning simply "Wait for Counter" is similar in purpose to Python's sleep but conceptually a little different. What you're actually doing here is waiting for the clock counter to reach a specific value. Normally you'll want to wait some multiple of seconds, and it just so happens that the value `clkfreq` always contains the number of clock ticks in a second. Multiply it by 10 and you get a 10 second wait, divide it by 10 and you get a tenth of a second wait, easy!

```spin
waitcnt(cnt + (clkfreq/10)) ' Wait 0.1 seconds
waitcnt(cnt + (clkfreq*10)) ' Wait 10 seconds
```

#Wiring up your Propeller HAT

To see the result of this code, you'll need an of LED plugged into outputs A0, like so:

Propeller Multicore Layout

#Uploading the code

To build and upload the code, you'll need either Propeller IDE on your desktop/laptop computer, or on your Raspberry Pi.

On the Pi it should be as simple as hitting the "Run" arrow ( the arrow pointing to the right ) and it'll upload
right onto your Propeller HAT. If this doesn't work you should try p1load. When you compile/build your program in
Propeller IDE it will generate a binary alongside the .spin file.

To flash a compiled binary you can use either p1load, supplied in this GitHub repository,
or the Python p1.loader from pip. You can do this with a binary built on the Pi, or with one you've uploaded
from your desktop/laptop computer.

If you have p1load installed you can flash this binary with:

```bash
p1load binary_file.binary
```

The default should ensure it gets uploaded to Propeller HAT and run.

If you don't, you can use "p1.loader" in Python, like so:

```bash
sudo pip install p1
sudo python -m p1.loader upload -g 17 binary_file.binary
```

You should see your LED blink!

#Further Reading

* <sup>1</sup> Watch a video about the difference between a compiler and interpreter: https://www.youtube.com/watch?v=_C5AHaS1mOA
* <sup>2</sup> "PLL" stands for "Phase-locked Loop", read more about it here: http://en.wikipedia.org/wiki/Phase-locked_loop

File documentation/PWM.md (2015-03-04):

#Propeller HAT PWM

Propeller HAT PWM is a Python library which flashes your Propeller HAT with a 30-pin
PWM driver library for controlling LEDs or servos.

It lets you drive 30 pins from A0 to A29, outputting PWM pulses, duty cycles or servo
commands with a simple serial protocol.

##Prerequisites

Propeller HAT PWM communicates over serial, so you don't need any extra wiring.

##Library Reference

```python
p1.pwm.duty(pin, duty, freq)
```

PWM the pin with a duty cycle of duty ( 0 to 100% ) at the defined frequency.

The value for requency is calculated like so: 1/Desired Frequency * 1000 * 1000

So if you want 50Hz, it's 1/50 * 1000 * 1000, or 20,000, eg: `p1.pwm.duty(0, 50, 20000)`.

```python
p1.pwm.pulse(pin,on_time,off_time)
```

Pulse a pin with on_time on duration and off_time off duration. Pulse accepts values between 0 and 65535.

The On and Off times are measured in units of 8.2us, giving a range of 0 to 537,387 ( or about 0.53 sec )<sup>1</sup>.

For example `p1.pwm.pulse(0,60975,60975)` is the closest you can get to toggling a pin every 0.5sec.

```python
p1.pwm.servo(pin, pulse)
```

Drive a servo with a specific pulse width in nanoseconds.
Look up your servo datasheet to see what pulse width corresponds to your desired angle.

####Notes

* <sup>1</sup> I may expand this to a 3-byte integer ranging from 0 to 16,777,215, or 0 to 137sec, but since
the Pi is fine at long pulse intervals it wouldn't be much use!

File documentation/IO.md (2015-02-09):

#Propeller HAT IO

Propeller HAT IO is a Python library which flashes your Propeller HAT with a 28-pin,
general purpose i2c GPIO driver.

It lets you control 28 pins from A0 to A27, setting them as Inputs or Outputs and
changing them from High to Low with simple i2c commands.

##Prerequisites

Propeller HAT IO requires two female-to-female jump wires making these connections:

* SDA on the left, to A29 along the bottom
* SCL on the left, to A28 along the bottom

This connects your Propeller HAT to the Raspberry Pi i2c bus. The Pi has built-in
pull-up resistors, so you don't need to add these yourself.

##Usage

Propeller HAT IO appears on your Raspberry Pi i2c bus 1 as address 0x17 by default.

To change pin direction and value, you must write registers 0-63, and to read pin
values you must read registers 64-96.

Pins 28, 29, 30 and 32 are not read or written because these are used for Serial 
and i2c communication.

Basic example to turn on pin 0 in bash:

```bash
sudo i2cset -y 1 0x17 0 1   # Write direction register
sudo i2cset -y 1 0x17 32 1  # Write value register
```
Or to read a pin in bash:

```bash
sudo i2cget -y 1 0x17 64    # Read pin 1
```

##Library Reference

```python
p1.io.setup(i2c_address)
```

Set up the i2c address of the Propeller HAT IO firmware. Only use this if you've
changed the firmware with an i2c address to suit your purposes.

```python
p1.io.mode(pin, mode)
```

Change the mode of pin <pin> to either mode 1, OUTPUT or mode 0, INPUT. You can use
p1.io.OUTPUT and p1.io.INPUT constants for this.

```python
p1.io.write(pin,value)
```
Write a value to <pin>. 1 = HIGH, 0 = LOW.

```python
p1.io.read(pin)
```
Read a value from <pin>. Returns 1 if the pin is read as HIGH or 0 if it is low.

**Note:** The Propeller does not have configurable internal pull-up/down resistors
on any of its IO pins. If you want to use an IO pin as an input, an appropriate
pull resistor is recommended to prevent it from floating.

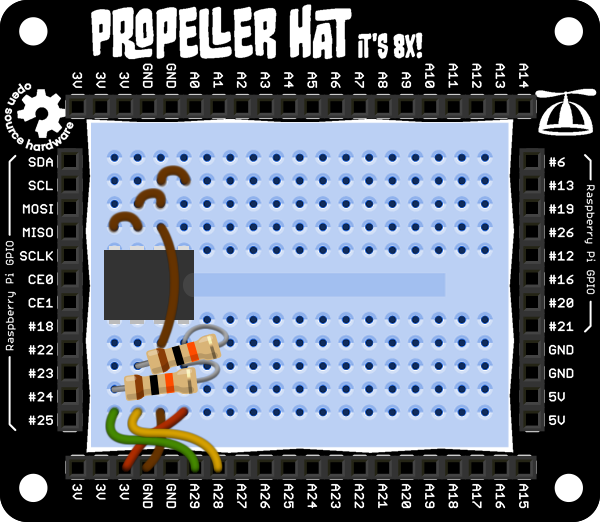
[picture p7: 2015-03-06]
documentation/images/propeller-hat-eeprom.png

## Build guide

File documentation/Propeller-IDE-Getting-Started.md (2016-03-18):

<!--
---
title: Getting started with Propeller IDE
handle: propeller-ide-getting-started
type: tutorial
summary: Learn how to install Propeller IDE, the development environment for Propeller HAT
author: Phil Howard
products: [propeller-hat]
tags: [Propeller HAT, Raspberry Pi, Microcontroller]
images: [images/tba.png]
difficulty: Intermediate
-->
#Propeller IDE Getting Started

##Raspberry Pi 3

The Raspberry Pi 3 does strange things with Serial for the benefit of Bluetooth. Unfortunately this completely trounces `propman` and any other Propeller HAT loader. You can fix it by making sure your Pi 3 is up-to-date ( `sudo apt-get update && sudo apt-get upgrade` ) then edit `/boot/config.txt` and adding the line:

```
dtoverlay=pi3-miniuart-bt
```

##Raspbian Jessie

With the [release of Raspbian Jessie](https://www.raspberrypi.org/downloads/raspbian/), Qt5.3 is available without having to mess about with adding new sources and installing things from backports. If you're using Raspbian Jessie then just:

* Download the latest Propeller IDE from: http://developer.parallax.com/propelleride/
* Install with: `sudo dpkg -i propelleride-*`
* Install dependencies with `sudo apt-get install -f`

That's it!

##Update

Propeller IDE 0.36.7 is the latest recommended build. These instructions have been updated to reflect the 0.36.7 install process. Enjoy!

You can find out more about the new Propeller IDE here: https://github.com/parallaxinc/PropellerIDE/releases/tag/0.36.7

##Preface

Learning to program isn't just about mastering a particular programming language
and applying it in every situation. It's about learning the key concepts
and applying them to a wealth of different situations in many languages.

The phrase "If you've only got a hammer, everything looks like a nail," springs to mind.
Different circumstances often beg for, or even require, different programming languages.

**SPIN**

The native language of the Parallax Propeller is SPIN. Spin is a little Pythonic in nature, 
it uses spaces and indentation a syntax.

It also borrows a lot of syntax quirks from other languages, and thus isn't going to be
familiar from the get go. That's no problem, you'll master it in no time!

**Propeller IDE**

The weapon-of-choice software for writing Propeller SPIN is the Open-Source Propeller IDE.
It runs on the Raspberry Pi pretty well, and we've made sure you can upload code right onto
your Propeller HAT painlessly so you can get programming quickly and avoid the hassle of setting up.

The great thing about Propeller IDE, SPIN and the Propeller is that they're close-knit and
unencumbered by the need to support lots of different processors. This makes compiling and uploading
SPIN code absolutely lightning fast- Arduino users will be simply blown away.

##First Steps

###Installing Pre-requisites ( Raspbian Wheezy only )

If you're running Raspbian Jessie, please skip to Installing Propeller IDE below.

Raspbian Wheezy needs a little helping hand with some of Propeller IDE's dependencies, but hopefully a future
release will see the end of these steps.

First, you'll need to install the `apt-transport-https` package for apt:

```
sudo apt-get install apt-transport-https
```

Next, add the following entries to `/etc/apt/sources.list` ( Note the "https://" and the lack of "main" ):

```
deb https://twolife.be/raspbian/ wheezy backports
deb-src https://twolife.be/raspbian/ wheezy backports
```

Add the repository key.

```bash
sudo apt-key adv --keyserver keyserver.ubuntu.com --recv-key 2578B775
```

And finally update and install Qt5 and its dependencies, plus libftdi1 for the loader.

```bash
sudo apt-get update
sudo apt-get install qt5-default qt5-qmake libqt5serialport5 libegl1-mesa libgles2-mesa libftdi1
```

Once that is done, you may want to comment out or remove the entries added to sources.list as they are no longer necessary. To do this, simply place a `#` before them, like so:

```
#deb https://twolife.be/raspbian/ wheezy backports
#deb-src https://twolife.be/raspbian/ wheezy backports
```

###Installing Propeller IDE

Now, head over to [developer.parallax.com/propelleride/](http://developer.parallax.com/propelleride/) and grab the latest 
version of Propeller IDE for the Raspberry Pi.

Propeller IDE download

It's easier if you grab the right URL, and use the wget command on your 
Raspberry Pi to download it. For example:

```bash
wget https://github.com/parallaxinc/PropellerIDE/releases/download/0.36.7/propelleride-0.36.7-armhf.deb
```

Once downloaded, you can install it with:

```bash
sudo dpkg -i propelleride-0.36.7-armhf.deb
```

###Turning off the Serial Terminal so you can talk to Propeller HAT

By default, the Raspberry Pi fires up a serial terminal on /dev/ttyAMA0. This is handy for debugging headless, but if you're using Propeller IDE and programming a Propeller HAT then you've likely got a monitor plugged in anyway!

The serial terminal must be disabled so that we can communicate with Propeller HAT. Fortunately, raspi-config makes this easy:

```bash
sudo raspi-config
```

Then navigate to Advanced Options, find the Serial option and disable it.

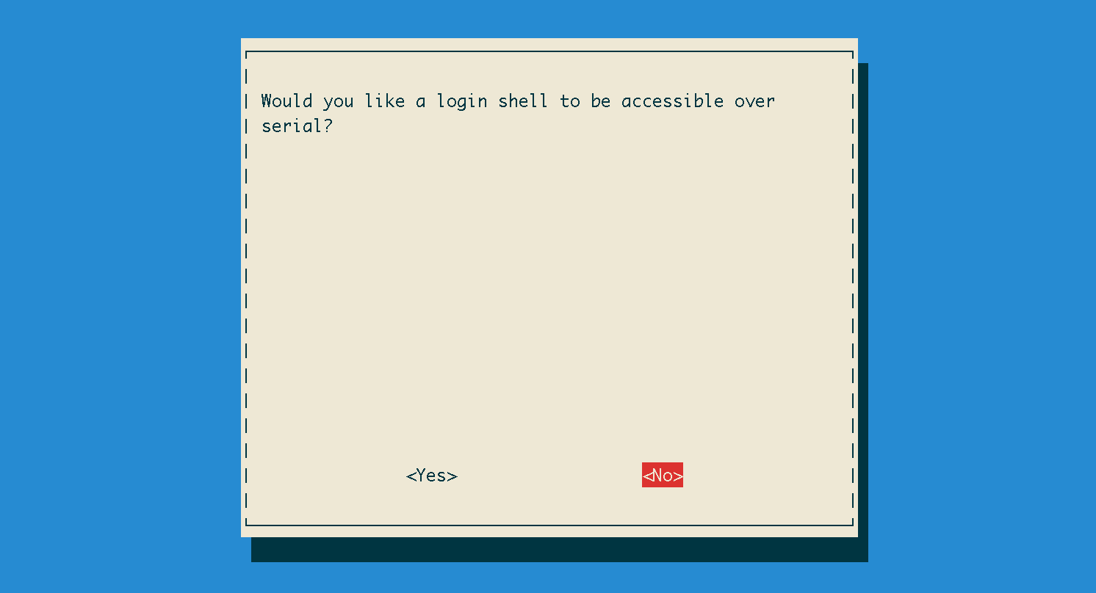
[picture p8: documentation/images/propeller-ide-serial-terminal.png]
Raspberry Pi, disable Serial Terminal


###Making sure propman can access your Raspberry Pi's GPIO pins

On Wheezy we need propman to run as root, so it can access the GPIO pin used for resetting Propeller HAT:

```bash
sudo chown root:root /usr/bin/propman
sudo chmod 4755 /usr/bin/propman
```

propman defaults to using GPIO pin 17, pulled low when built for the Raspberry Pi, so this is all we need to do. You're good to go! Uploading code is as simple as:

```bash
propman my-binary-file.binary
```

And to compile a SPIN file to a binary outside of the IDE, you can:

```bash
openspin my-spin-file.spin
```

#What next?

* [Your first SPIN program](/documentation/Your-first-SPIN-program.md)

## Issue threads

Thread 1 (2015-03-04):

libftdi1 dependency error

sandyjmacdonald, 2015-03-04:
Hey Phil. I get the following error when installing the Propeller IDE:

```
Selecting previously unselected package propelleride.
(Reading database ... 85351 files and directories currently installed.)
Unpacking propelleride (from propelleride-0.25.1-0-g5442b03-armhf.deb) ...
dpkg: dependency problems prevent configuration of propelleride:
 propelleride depends on libftdi1; however:
  Package libftdi1 is not installed.

dpkg: error processing propelleride (--install):
 dependency problems - leaving unconfigured
Processing triggers for desktop-file-utils ...
Processing triggers for menu ...
Errors were encountered while processing:
 propelleride
```

Easily fixed with `sudo apt-get install libftdi1` and I reckon if you add it to the end of the ```sudo apt-get install qt5-default qt5-qmake libegl1-mesa libgles2-mesa``` [here](https://github.com/pimoroni/propeller-hat/blob/master/documentation/Propeller-IDE-Getting-Started.md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) then it should all just work.

Gadgetoid, 2015-03-04:
D'oh! Thank you! Good spot. I always miss these, despite multiple installations, since I often have libftdi1 preinstalled!

Closed 2015-03-10.

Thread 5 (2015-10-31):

feature request: a C/C++ API lib for Raspbian

shiftleftplusone, 2015-10-31:
feature request:
a gcc/g++  C/C++ API lib for Raspbian would be very much appreciated!
(compatibility to pthread, wiringPi and pigpio necessary)

Gadgetoid, 2016-03-22:
This is an interesting suggestion. Would you envision a "Firmata" style API where the C/C++ API controls the Propeller HAT via a pre-uploaded binary, or something else?

The Python SerialIO library contains a binary blob which it uploads to the Propeller before taking control, via serial, of its GPIO pins with a simple protocol. This could be replicated in C quite trivially.

shiftleftplusone, 2016-03-25:
I don't know firmata,
something like the Arduino Sketch API commands would be nice
but either suggestions are appreciated,
most of all: there will be simple C commands available!

Closed 2017-05-03.

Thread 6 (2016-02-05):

Vncserver with Propeller

optimho, 2016-02-05:
I am using Jessie and connecting to the Raspberry with Vncserver and the keyboard is wrong.
The letters I type are not the ones that end up on the editor. This is not an issue with SimpleIDE or any other program I access with VncServer.

Gadgetoid, 2016-02-24:
I came across this one before, and don't know if there's any way to fix it. I believe it's related to Qt plugins or something currently beyond my understanding. It might be worth filing an issue against the PropellerIDE project to see if anyone can help: https://github.com/parallaxinc/PropellerIDE/issues

Closed 2016-07-06.

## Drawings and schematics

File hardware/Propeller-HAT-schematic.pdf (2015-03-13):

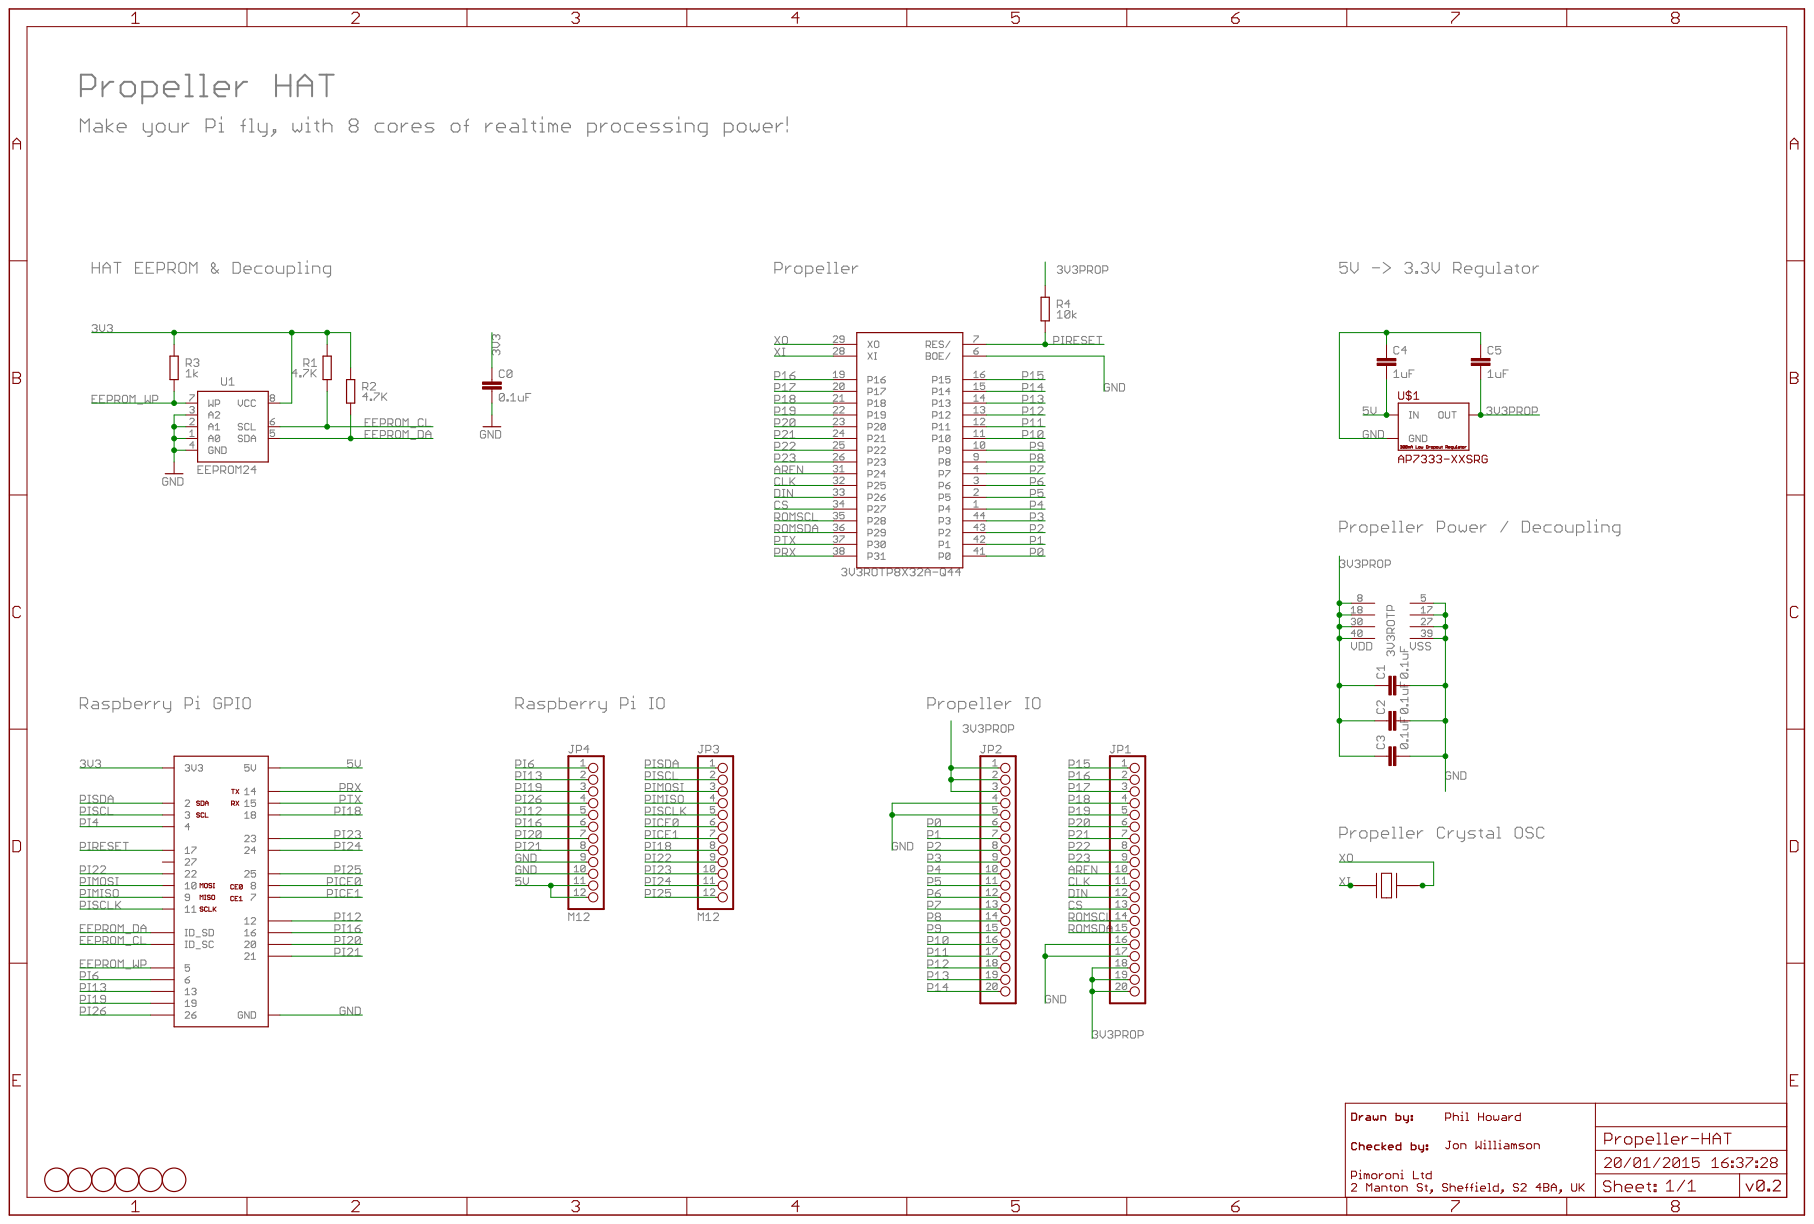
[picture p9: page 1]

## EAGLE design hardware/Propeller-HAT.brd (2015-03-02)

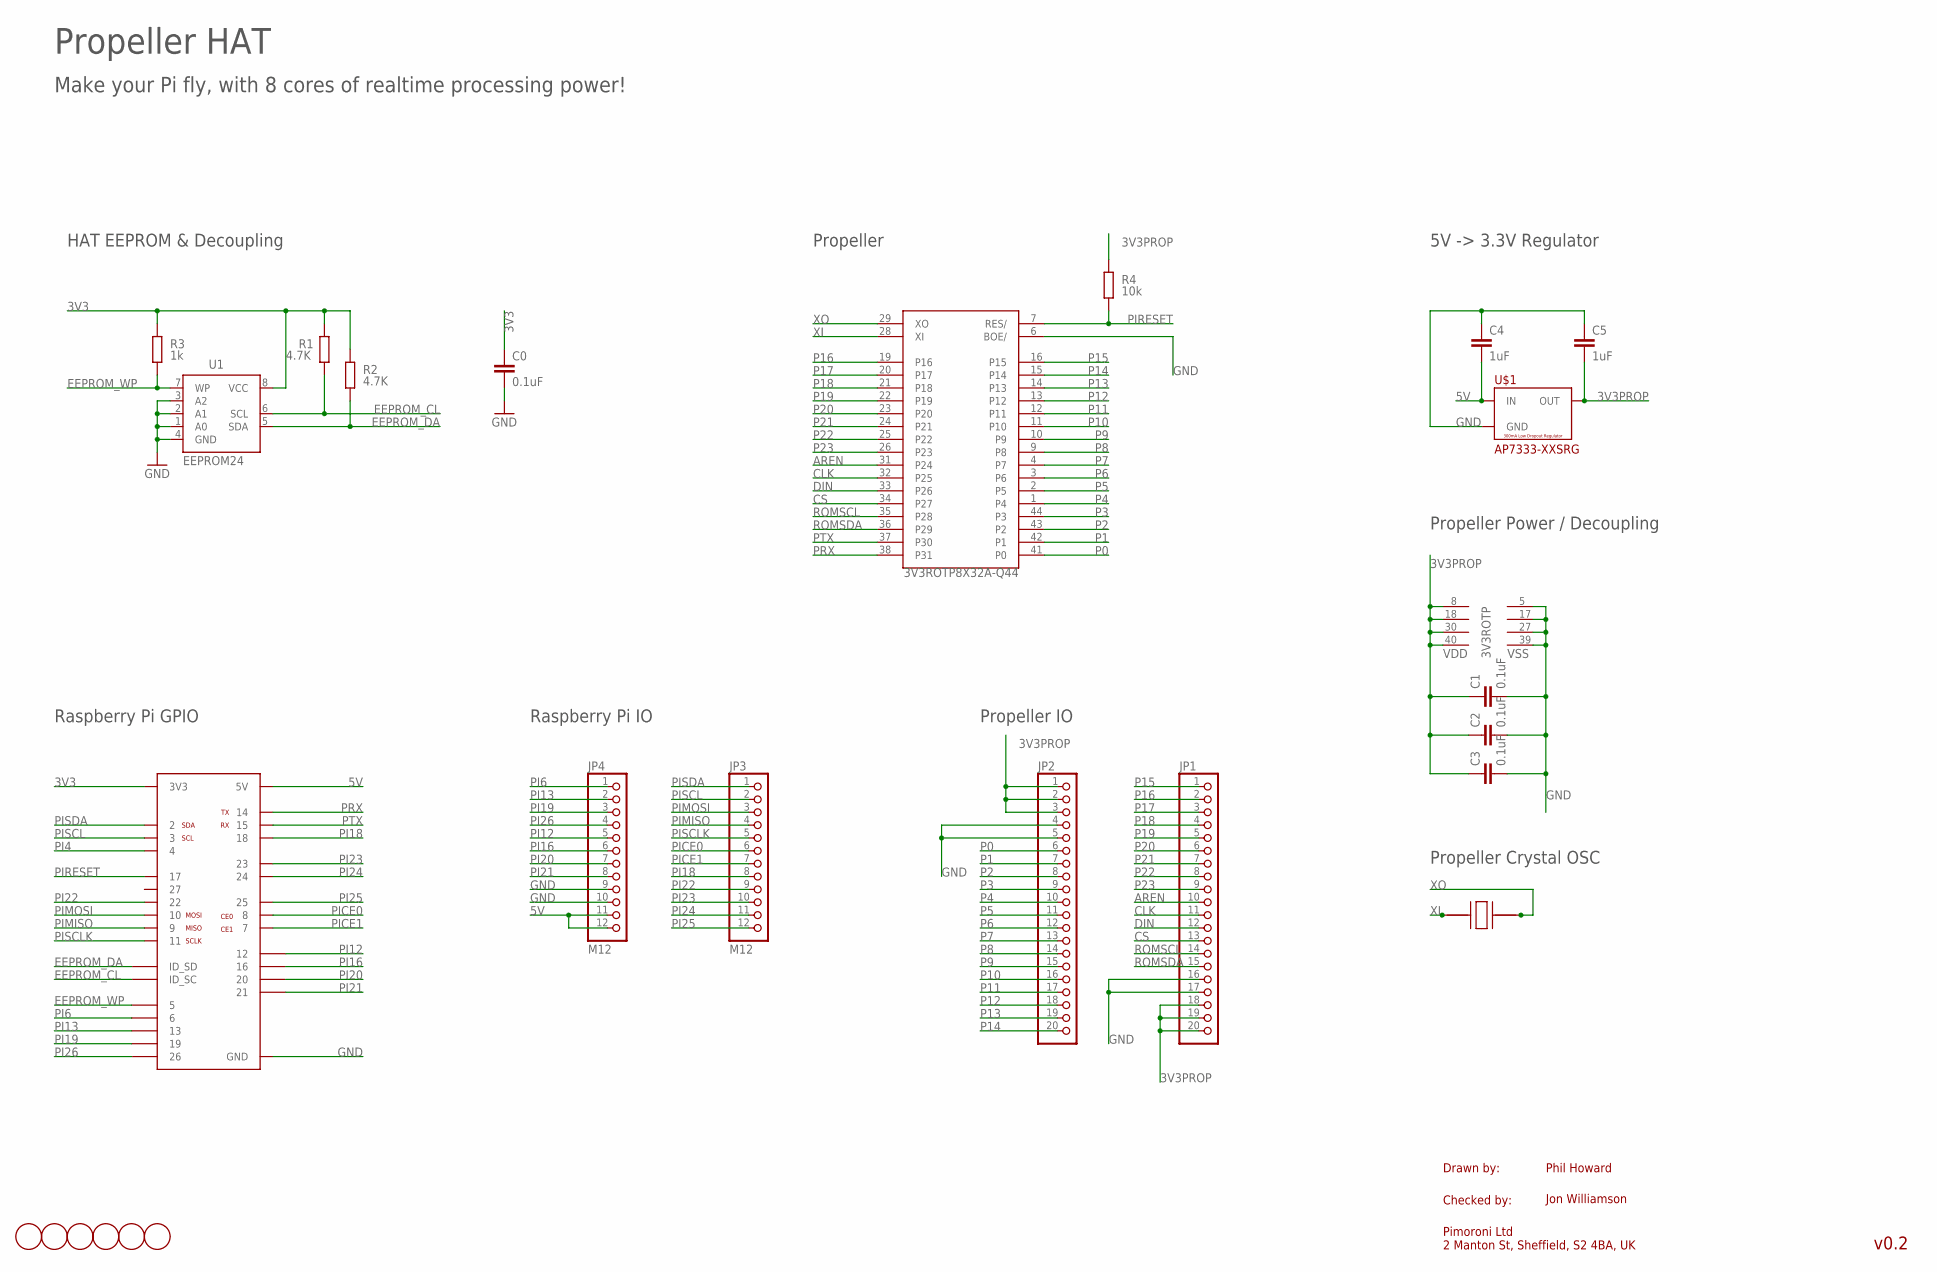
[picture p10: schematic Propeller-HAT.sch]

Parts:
3V3ROT: P8X32A-Q44
C0, C1, C2, C3: 0.1uF; C0603K
C4, C5: 1uF; C0603K
JP1, JP2: PINHD-1X20-BIG; 1X20-BIG
JP3, JP4: M12
R1, R2: 4.7K; R0603; TOLERANCE 5%
R3: 1k; R0603; TOLERANCE 5%
R4: 10k; R0603; TOLERANCE 5%
U1: EEPROM24; SOIC8
U$1: AP7333-XXSRG; SOT23
U$2: RPIGPIOPINHD-2X20-SMD-FLIPPED; FCI_89898_313LF_40P_CONNECTOR_SMT_FLIPPED
U$3, U$4, U$5, U$6, U$7, U$8: FIDUCIAL1MM; FIDUCIAL-1MM
U$9: ABLS3-XXXMHZ-D4Y-T

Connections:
3V3: C0.1, R1.2, R2.2, R3.2, U1.8 (VCC), U$2.P1_3V3 (3V3), U$2.P17_3V3 (3V3)
3V3PROP: 3V3ROT.8 (VDD), 3V3ROT.18 (VDD), 3V3ROT.30 (VDD), 3V3ROT.40 (VDD), C1.1, C2.1, C3.1, C5.2, JP1.18, JP1.19, JP1.20, JP2.1, JP2.2, JP2.3, R4.2, U$1.2 (OUT)
5V: C4.2, JP4.11, JP4.12, U$1.3 (IN), U$2.P2_5V (5V), U$2.P4_5V (5V)
AREN: 3V3ROT.31 (P24), JP1.10
CLK: 3V3ROT.32 (P25), JP1.11
CS: 3V3ROT.34 (P27), JP1.13
DIN: 3V3ROT.33 (P26), JP1.12
EEPROM_CL: R1.1, U1.6 (SCL), U$2.P28_IDSC (ID_SC)
EEPROM_DA: R2.1, U1.5 (SDA), U$2.P27_IDSD (ID_SD)
EEPROM_WP: R3.1, U1.7 (WP), U$2.P29_GPIO5 (5)
GND: 3V3ROT.5 (VSS), 3V3ROT.6 (BOE/), 3V3ROT.17 (VSS), 3V3ROT.27 (VSS), 3V3ROT.39 (VSS), C0.2, C1.2, C2.2, C3.2, C4.1, C5.1, JP1.16, JP1.17, JP2.4, JP2.5, JP4.9, JP4.10, U1.1 (A0), U1.2 (A1), U1.3 (A2), U1.4 (GND), U$1.1 (GND), U$2.P6_GND (GND), U$2.P9_GND (GND), U$2.P14_GND (GND), U$2.P20_GND (GND), U$2.P25_GND (GND), U$2.P30_GND (GND), U$2.P34_GND (GND), U$2.P39_GND (GND)
P0: 3V3ROT.41 (P0), JP2.6
P1: 3V3ROT.42 (P1), JP2.7
P2: 3V3ROT.43 (P2), JP2.8
P3: 3V3ROT.44 (P3), JP2.9
P4: 3V3ROT.1 (P4), JP2.10
P5: 3V3ROT.2 (P5), JP2.11
P6: 3V3ROT.3 (P6), JP2.12
P7: 3V3ROT.4 (P7), JP2.13
P8: 3V3ROT.9 (P8), JP2.14
P9: 3V3ROT.10 (P9), JP2.15
P10: 3V3ROT.11 (P10), JP2.16
P11: 3V3ROT.12 (P11), JP2.17
P12: 3V3ROT.13 (P12), JP2.18
P13: 3V3ROT.14 (P13), JP2.19
P14: 3V3ROT.15 (P14), JP2.20
P15: 3V3ROT.16 (P15), JP1.1
P16: 3V3ROT.19 (P16), JP1.2
P17: 3V3ROT.20 (P17), JP1.3
P18: 3V3ROT.21 (P18), JP1.4
P19: 3V3ROT.22 (P19), JP1.5
P20: 3V3ROT.23 (P20), JP1.6
P21: 3V3ROT.24 (P21), JP1.7
P22: 3V3ROT.25 (P22), JP1.8
P23: 3V3ROT.26 (P23), JP1.9
PI4: U$2.P7_GPIO4 (4)
PI6: JP4.1, U$2.P31_GPIO6 (6)
PI12: JP4.5, U$2.P32_GPIO12 (12)
PI13: JP4.2, U$2.P33_GPIO13 (13)
PI16: JP4.6, U$2.P36_GPIO16 (16)
PI18: JP3.8, U$2.P12_GPIO18 (18)
PI19: JP4.3, U$2.P35_GPIO19 (19)
PI20: JP4.7, U$2.P38_GPIO20 (20)
PI21: JP4.8, U$2.P40_GPIO21 (21)
PI22: JP3.9, U$2.P15_GPIO22 (22)
PI23: JP3.10, U$2.P16_GPIO23 (23)
PI24: JP3.11, U$2.P18_GPIO24 (24)
PI25: JP3.12, U$2.P22_GPIO25 (25)
PI26: JP4.4, U$2.P37_GPIO26 (26)
PICE0: JP3.6, U$2.P24_GPIO8_SPI0_CE0 (8)
PICE1: JP3.7, U$2.P26_GPIO7_SPI0_CE1 (7)
PIMISO: JP3.4, U$2.P21_GPIO9_SPI0_MISO (9)
PIMOSI: JP3.3, U$2.P19_GPIO10_SPI0_MOSI (10)
PIRESET: 3V3ROT.7 (RES/), R4.1, U$2.P11_GPIO17 (17)
PISCL: JP3.2, U$2.P5_GPIO3_SCL (3)
PISCLK: JP3.5, U$2.P23_GPIO11_SPI0_SCLK (11)
PISDA: JP3.1, U$2.P3_GPIO2_SDA (2)
PRX: 3V3ROT.38 (P31), U$2.P8_GPIO14_UART0_TXD (14)
PTX: 3V3ROT.37 (P30), U$2.P10_GPIO15_UART0_RXD (15)
ROMSCL: 3V3ROT.35 (P28), JP1.14
ROMSDA: 3V3ROT.36 (P29), JP1.15
XI: 3V3ROT.28 (XI), U$9.P$1 (1)
XO: 3V3ROT.29 (XO), U$9.P$2 (3)

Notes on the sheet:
Drawn by:
Checked by:
Pimoroni Ltd 2 Manton St, Sheffield, S2 4BA, UK
Phil Howard
v0.2
Propeller HAT
HAT EEPROM & Decoupling
Raspberry Pi GPIO
Make your Pi fly, with 8 cores of realtime processing power!
Jon Williamson
Propeller Power / Decoupling
Propeller Crystal OSC
5V -> 3.3V Regulator
Propeller IO
Raspberry Pi IO
Propeller

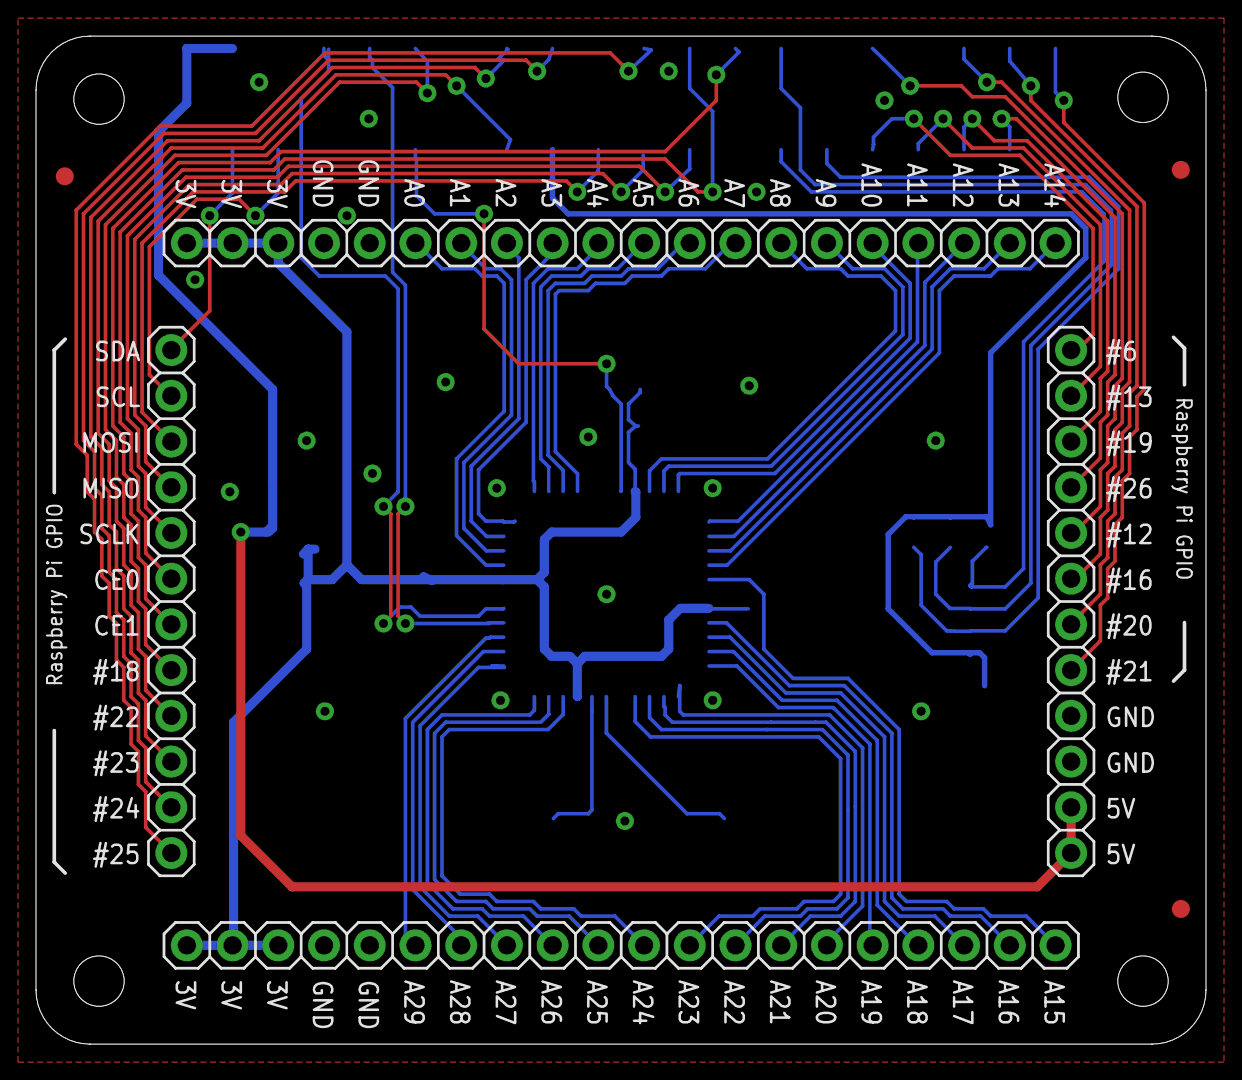
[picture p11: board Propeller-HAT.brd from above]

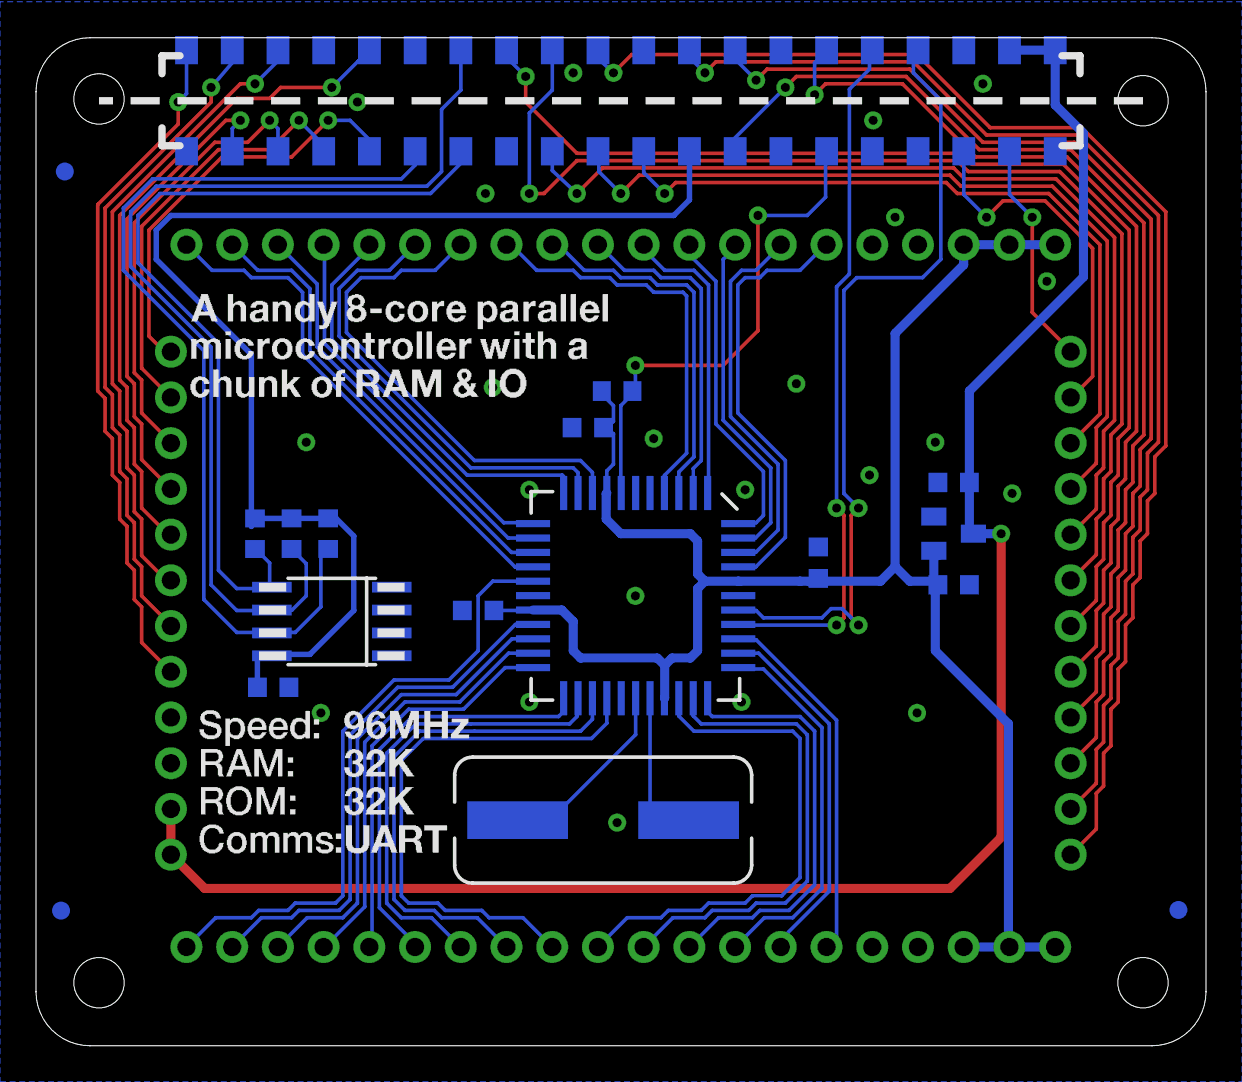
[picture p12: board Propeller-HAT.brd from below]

Board: 2 copper layers, 65.0 x 56.0 mm, 25 parts (18 on the bottom side), 62 nets.

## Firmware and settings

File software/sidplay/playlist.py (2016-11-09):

#!/usr/bin/env python

import subprocess
import time
from sys import exit, version_info

try:
    import smbus
except ImportError:
    if version_info[0] < 3:
        exit("This library requires python-smbus\nInstall with: sudo apt-get install python-smbus")
    elif version_info[0] == 3:
        exit("This library requires python3-smbus\nInstall with: sudo apt-get install python3-smbus")

try:
    import RPi.GPIO as GPIO
except ImportError:
    exit("This library requires the RPi.GPIO module\nInstall with: sudo pip install RPi.GPIO")

    
GPIO.setmode(GPIO.BCM)
GPIO.setup(17,GPIO.OUT,initial=GPIO.HIGH)
GPIO.output(17,GPIO.LOW)
time.sleep(0.01)
GPIO.output(17,GPIO.HIGH)
time.sleep(1)

bus = smbus.SMBus(1)

#proc = subprocess.Popen(['p1load','-e','-r','SIDcogSlave.binary'])
#proc.wait()

duration = 120

# File, Time seconds, speed hz
playlist = [
    ('Eskimonika',220,250),
    ('Boten_Anna',100,duration),
    ('All_That_She_Wants_8580',120,duration),
    ('Scream',60,duration),
    ('Polyphonica',60,50),
    ('Alternative_Fuel',50,duration),
    ('Vibralux',50,duration),
    ('Super_Mario_Land',50,duration)
]

proc = None

while True:
  for song, speed, duration in playlist:
    print("Playing {} for {}".format(song, duration))
    proc = subprocess.Popen(['./sidplay','sid/{}.dmp'.format(song),str(speed),str(duration)])
    while proc.poll() is None:
      try:
        button = bus.read_byte_data(0x14,0x00)
        if button:
          proc.kill()
          while bus.read_byte_data(0x14,0x00):
            pass
          continue
      except IOError:
        pass
      time.sleep(0.01)

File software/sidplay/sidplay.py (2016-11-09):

#!/usr/bin/env python

import sys
import time

try:
    import serial
except ImportError:
    sys.exit("This library requires the serial module\nInstall with: sudo pip install pyserial")

import p1.loader


print('Setting up Propeller HAT')
l = p1.loader.Loader('/dev/ttyAMA0',17)
l.upload(path='SIDcogSlave.binary',progress=p1.loader.print_status)
time.sleep(0.1)

# Comment the line below to enable the (slow) Python sid player
exit('Now use ./sidplay tunes/<filename> to play a tune!')

play_rate = 50 #Hz

if len(sys.argv) < 2:
  exit("Usage: " + sys.argv[0] + " <dump>")

s = serial.Serial('/dev/ttyAMA0',115200)

f = open(sys.argv[1],'rb')

d = f.read()

f.close()

reg_size = 25


def chunks(l, n):
  for i in range(0, len(l), n):
    yield l[i:i+n]

chunks = list(map(lambda x: chr(13) + 'SDMP' + ''.join(x), chunks(d, reg_size)))

for chunk in chunks:
  print(list(ord(x) for x in chunk))
  s.write(chunk)
  s.flush()
  time.sleep(1.0/play_rate)

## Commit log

2015-03-02 Initial commit of tidied schematic and board files for Cadsoft Eagle
    [Propeller-HAT.brd, Propeller-HAT.sch]
2015-03-04 Update with dependency install for libftdi1
    Thanks Sandy! Fix for https://github.com/pimoroni/propeller-hat/issues/1
2015-03-05 Fixed pin numbers in exmaples from bytes to longs, they're masks doh
2015-03-13 Added PDF schematic
2015-03-13 Corrected EEPROM part number to I2C version
2015-03-13 Propeller HAT Fritzing part and SVG
2015-05-03 Update Serial-IO.md
    not sure what is intended but I guess it should either be '30 and 31' or '31 and 32'... the former seems strictly logical given the example and the context of the word 'pin'?
2015-05-03 Update Propeller-IDE-Getting-Started.md
    I'm not a fan of adding repository to sources.list and leaving them active once they have served their purpose. In this case, at thispoint in time they would enforce upgardes of the follwoing on my s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
    libraspberrypi-bin libraspberrypi-dev libraspberrypi-doc libraspberrypi0 raspberrypi-bootloader
    maybe I'm funny and all that but I'm not keen on it ;-)
2016-08-24 added makefile for io-pwm

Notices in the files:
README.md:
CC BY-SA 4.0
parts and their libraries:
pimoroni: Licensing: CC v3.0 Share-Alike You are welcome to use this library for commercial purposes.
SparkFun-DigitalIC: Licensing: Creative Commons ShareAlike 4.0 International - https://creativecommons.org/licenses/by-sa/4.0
